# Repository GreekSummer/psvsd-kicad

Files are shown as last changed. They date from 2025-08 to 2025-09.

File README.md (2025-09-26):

# PSVSD KiCad source

This is a fork of [Yinfanlu's PSVSD adapter](https://github.com/yifanlu/psvsd/). Its main purpose is to adapt the original Eagle Autodesk files to KiCad, which is open source and free. 

The conversion was done using KiCad's own importer. The result was mostly complete with various issues that had to be manually corrected. The result has not yet been produced, so assume there are still issues.

I removed the debug headers to simplify the board. Most people do not need these. I also replaced the SD slot with one that is easier to find and source.

A big problem with these is sourcing the main USB-to-SD IC. As of August 15th 2025, I was able to find the GL823A-QFN24 on AliExpress for $3.30 per IC. The rest of the parts cost ~$5.03 on DigiKey.

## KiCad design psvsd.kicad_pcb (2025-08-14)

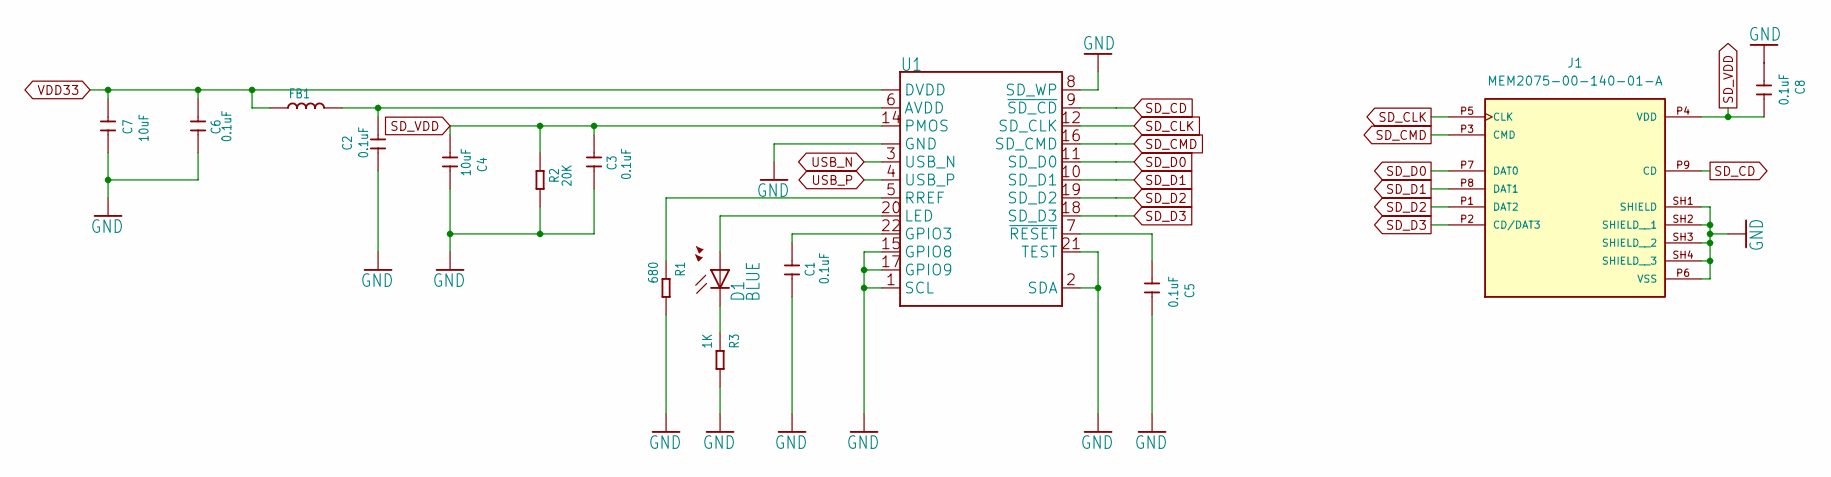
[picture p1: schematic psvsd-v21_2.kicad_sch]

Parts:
C1, C2, C3, C5, C6, C8: 0.1uF; C0603_464
C4, C7: 10uF; C0603_464
D1: BLUE; CHIP-LED0603_259
FB1: SMD-FERRITE-BEAD-2500R-50MA(0603); L0603_471
J1: MEM2075-00-140-01-A; GCT_MEM2075-00-140-01-A; PARTREV A
R1: 680; R0603_474
R2: 20K; R0603_474
R3: 1K; R0603_474
U1: GL823(A)OG; QFN-24

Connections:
GND: C1.2, C2.2, C3.2, C4.2, C5.2, C6.2, C7.2, C8.2, J1.P6 (VSS), J1.SH1 (SHIELD), J1.SH2 (SHIELD__1), J1.SH3 (SHIELD__2), J1.SH4 (SHIELD__3), R1.2, R2.2, R3.2, U1.1 (SCL), U1.2 (SDA), U1.8 (SD_WP), U1.15 (GPIO8), U1.17 (GPIO9), U1.21 (TEST), U1.24 (GND), U1.25 (GND); also elsewhere on the board
unnamed: D1.C, R3.1
unnamed: C2.1, FB1.2, U1.6 (AVDD)
unnamed: C1.1, U1.22 (GPIO3)
unnamed: D1.A, U1.20 (LED)
unnamed: R1.1, U1.5 (RREF)
unnamed: C5.1, U1.7 (~RESET)
SD_CD: J1.P9 (CD), U1.9 (~SD_CD)
SD_CLK: J1.P5 (CLK), U1.12 (SD_CLK)
SD_CMD: J1.P3 (CMD), U1.16 (SD_CMD)
SD_D0: J1.P7 (DAT0), U1.11 (SD_D0)
SD_D1: J1.P8 (DAT1), U1.10 (SD_D1)
SD_D2: J1.P1 (DAT2), U1.19 (SD_D2)
SD_D3: J1.P2 (CD/DAT3), U1.18 (SD_D3)
SD_VDD: C3.1, C4.1, C8.1, J1.P4 (VDD), R2.1, U1.14 (PMOS)
USB_N: U1.3 (USB_N); also elsewhere on the board
USB_P: U1.4 (USB_P); also elsewhere on the board
VDD33: C6.1, C7.1, FB1.1, U1.13 (DVDD), U1.23 (DVDD); also elsewhere on the board

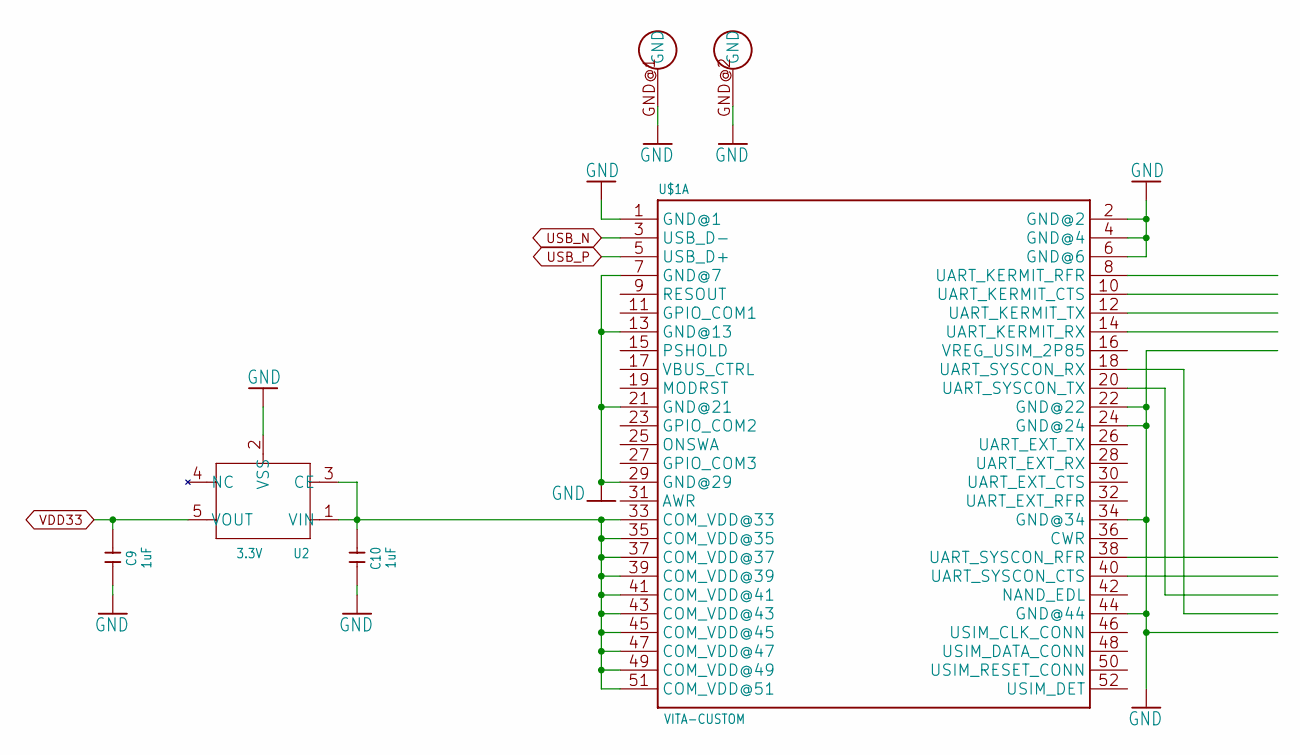
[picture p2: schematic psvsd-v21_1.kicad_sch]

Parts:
C9, C10: 1uF; C0603_464
U2: 3.3V; SOT-23-5_470
U$1: VITA-CUSTOM; VITA-MINI-PCI-E

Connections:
GND: C9.2, C10.2, U2.2 (VSS), U$1.1 (GND@1), U$1.2 (GND@2), U$1.4 (GND@4), U$1.6 (GND@6), U$1.7 (GND@7), U$1.13 (GND@13), U$1.21 (GND@21), U$1.22 (GND@22), U$1.24 (GND@24), U$1.29 (GND@29), U$1.34 (GND@34), U$1.44 (GND@44), U$1.GND@1 (GND), U$1.GND@2 (GND); also elsewhere on the board
unnamed: C10.1, U2.1 (VIN), U2.3 (CE), U$1.33 (COM_VDD@33), U$1.35 (COM_VDD@35), U$1.37 (COM_VDD@37), U$1.39 (COM_VDD@39), U$1.41 (COM_VDD@41), U$1.43 (COM_VDD@43), U$1.45 (COM_VDD@45), U$1.47 (COM_VDD@47), U$1.49 (COM_VDD@49), U$1.51 (COM_VDD@51)
USB_N: U$1.3 (USB_D-); also elsewhere on the board
USB_P: U$1.5 (USB_D+); also elsewhere on the board
VDD33: C9.1, U2.5 (VOUT); also elsewhere on the board

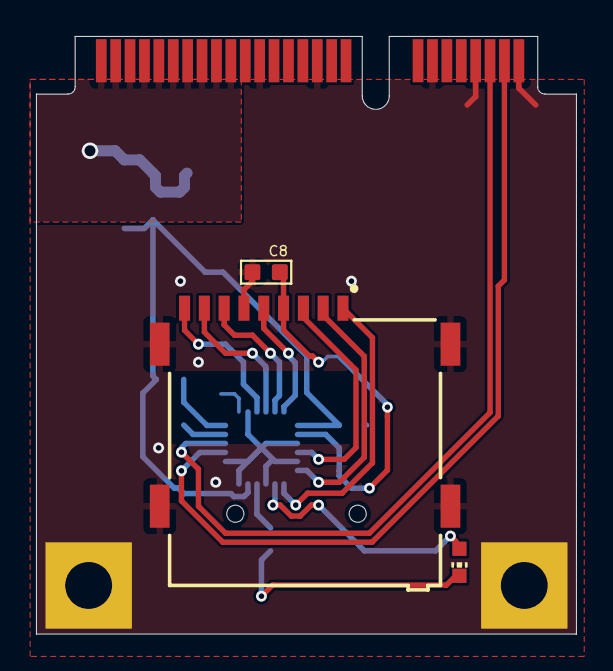
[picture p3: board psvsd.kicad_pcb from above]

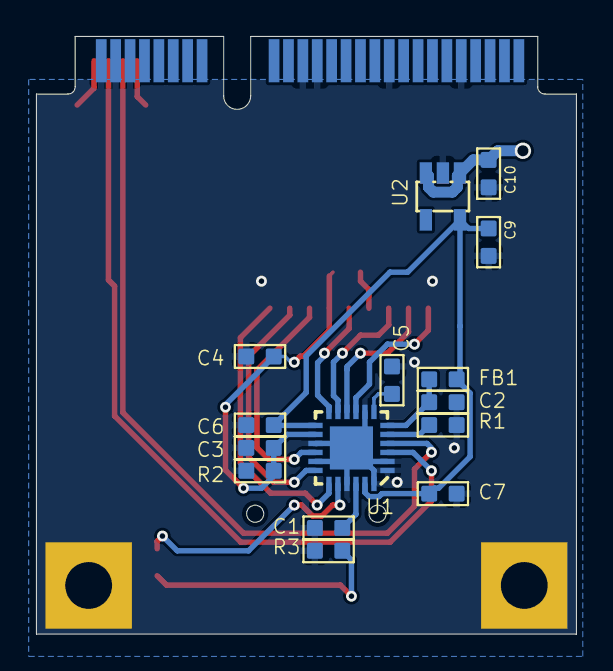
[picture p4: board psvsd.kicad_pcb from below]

Board: 2 copper layers, 30.0 x 33.2 mm, 19 parts (15 on the bottom side), 19 nets.
